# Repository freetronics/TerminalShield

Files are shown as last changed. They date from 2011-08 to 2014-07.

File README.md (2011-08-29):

Freetronics Terminal Shield
===========================
Copyright 2011 Freetronics Pty Ltd  
Freetronics site:  <www.freetronics.com>  
Freetronics email: <info@freetronics.com>  

A general-purpose prototyping shield for the Arduino Uno, Freetronics
Eleven, and other compatible boards based on the same header format,
with handy screw terminals for connecting external wires.

Features:

 * Reset button wired through to Arduino reset pin.
 * Red, green, and blue general-purpose SMT LEDs with current-limiting
   resistors (drive HIGH to illuminate).
 * Blue "power on" LED with current-limiting resistor.
 * Large GND and 5V power rails alongside the prototyping area.
 * 2 x 100nF bypass/smoothing capacitors on supply rails.
 * Overlay guide where you need it: both top and bottom.

More information is available on our product page at:

  http://www.freetronics.com/terminalshield

The "docs" folder within this repository includes a handy copy of the
schematic in PDF format and image(s) of the pcb.

INSTALLATION
------------
The design is saved as an EAGLE project. EAGLE PCB design software is
available from www.cadsoftusa.com free for non-commercial use. To use
this project download it and place the directory containing these files
into the "eagle" directory on your computer. Then open EAGLE and
navigate to Projects -> eagle -> TerminalShield.

DISTRIBUTION
------------
The specific terms of distribution of this project are governed by the
license referenced below.

LICENSE
-------
Licensed under the TAPR Open Hardware License (www.tapr.org/OHL).
The "license" folder within this repository also contains a copy of
this license in plain text format.

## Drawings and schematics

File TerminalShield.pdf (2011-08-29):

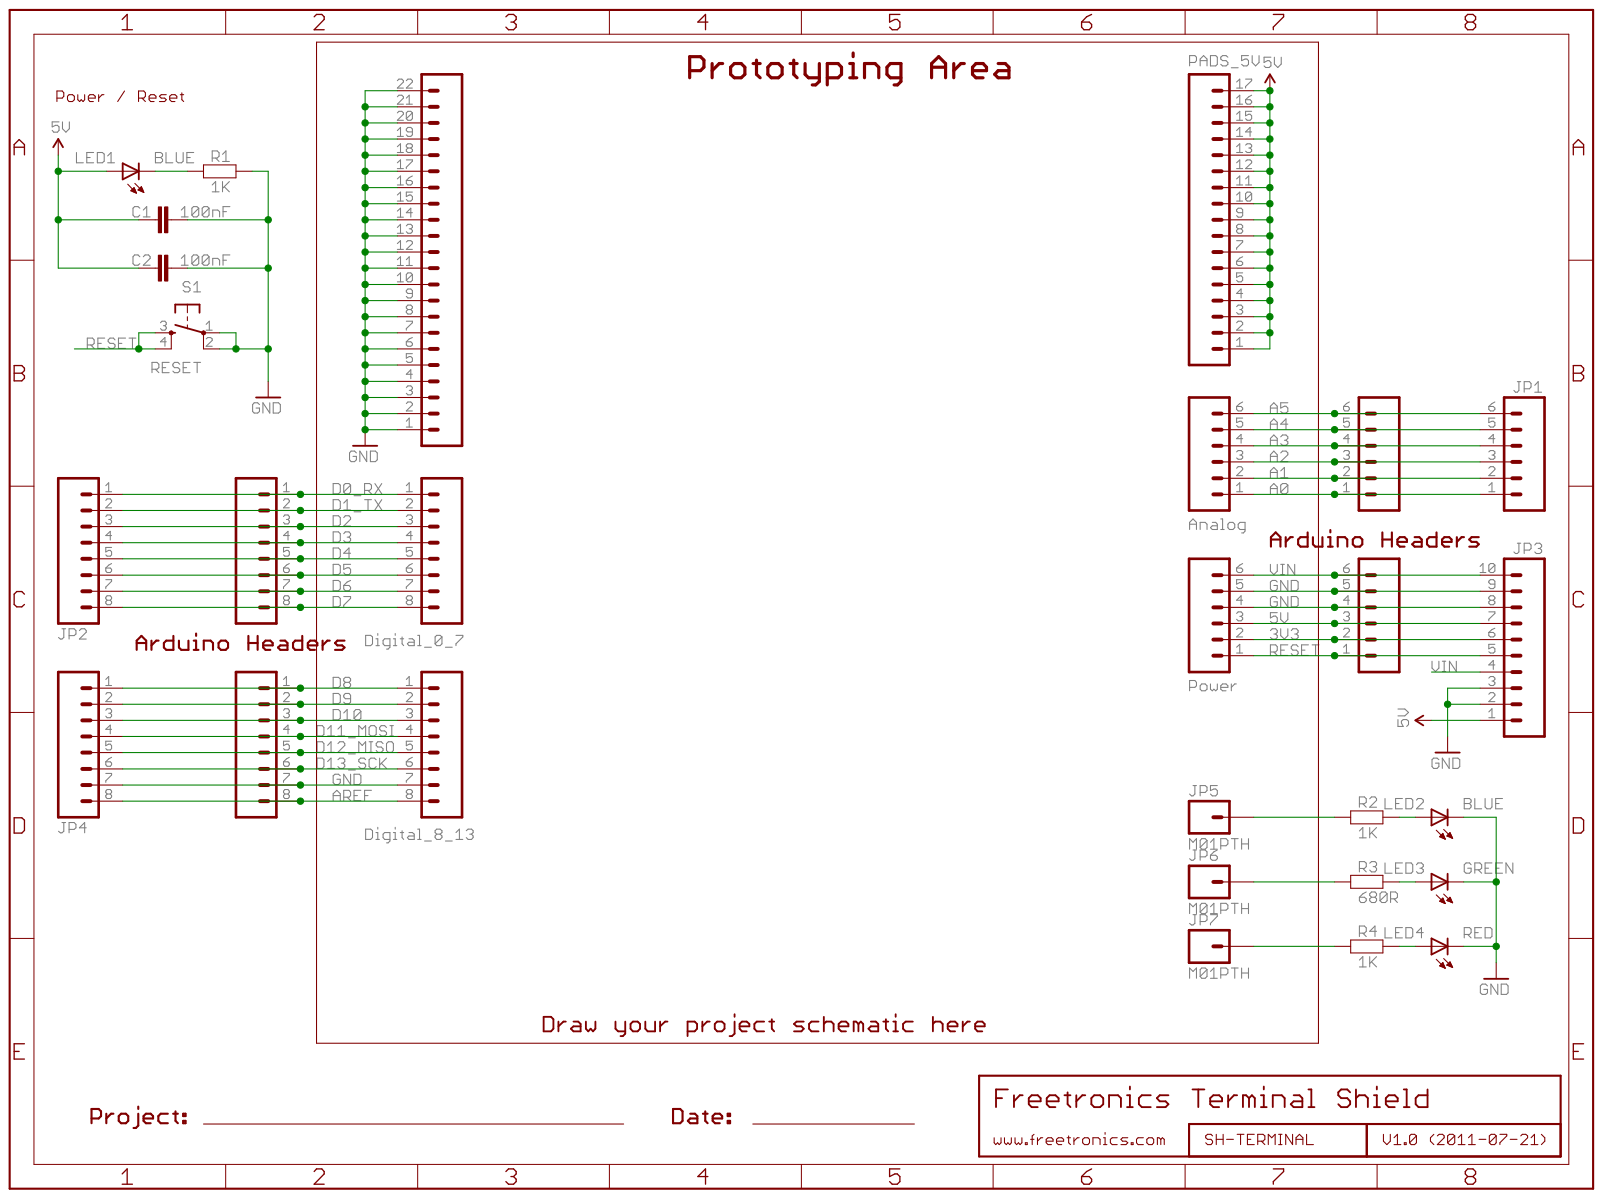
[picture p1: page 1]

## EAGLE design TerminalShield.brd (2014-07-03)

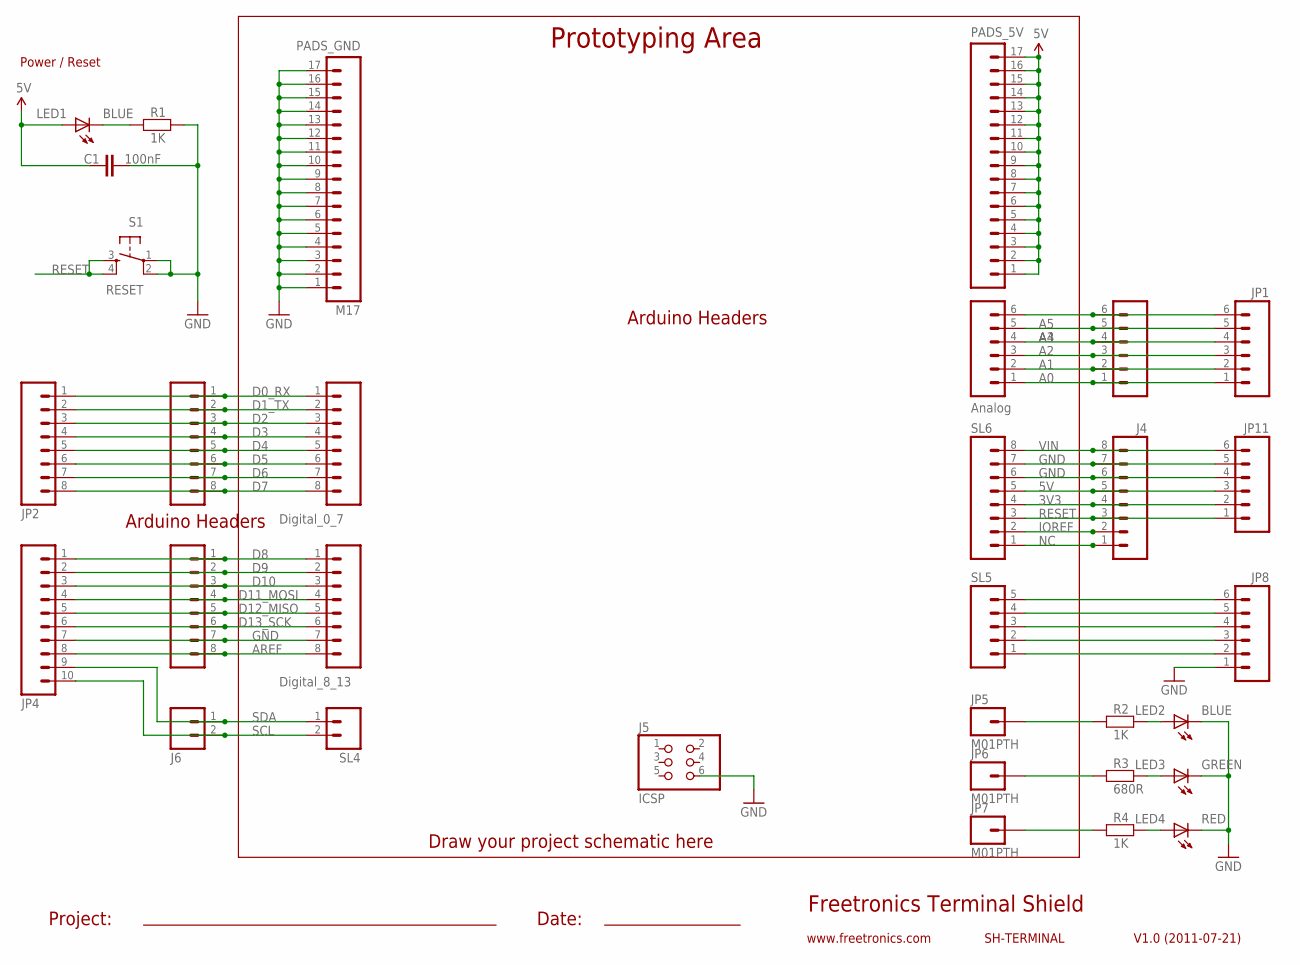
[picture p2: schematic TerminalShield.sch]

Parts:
C1: 100nF; 0603
J1: Analog; 1X06
J2: Digital_0_7; 1X08
J3: Digital_8_13; 1X08
J4: M08STD; 1X08
J5: ICSP; 2X03
J6: M02PTH; 1X02
JP1, JP8, JP11: M06; TERMINALBLOCK_3.5MM_6
JP2: M08; TERMINALBLOCK_3.5MM_8
JP4: M10; TERMINALBLOCK_3.5MM_10
JP5, JP6, JP7: M01PTH; 1X01
LED1, LED2: BLUE; LED-0603
LED3: GREEN; LED-0603
LED4: RED; LED-0603
PADS_5V: M17; 1X17
PADS_GND: M17; 1X17
R1, R2, R4: 1K; 0603
R3: 680R; 0603
S1: RESET; TACTILE_SWITCH_SMD
SL1: Analog; 1X06
SL2: Digital_0_7; 1X08
SL3: Digital_8_13; 1X08
SL4: M02PTH; 1X02
SL5: M05PTH; 1X05
SL6: M08STD; 1X08

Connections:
3V3: J4.4, JP11.2, SL6.4
5V: C1.1, J4.5, JP11.3, LED1.A, PADS_5V.1, PADS_5V.2, PADS_5V.3, PADS_5V.4, PADS_5V.5, PADS_5V.6, PADS_5V.7, PADS_5V.8, PADS_5V.9, PADS_5V.10, PADS_5V.11, PADS_5V.12, PADS_5V.13, PADS_5V.14, PADS_5V.15, PADS_5V.16, PADS_5V.17, SL6.5
A0: J1.1, JP1.1, SL1.1
A1: J1.2, JP1.2, SL1.2
A2: J1.3, JP1.3, SL1.3
A3: J1.4, JP1.4, SL1.4
A4: J1.5, JP1.5, SL1.5
A5: J1.6, JP1.6, SL1.6
AREF: J3.8, JP4.8, SL3.8
D0_RX: J2.1, JP2.1, SL2.1
D1_TX: J2.2, JP2.2, SL2.2
D2: J2.3, JP2.3, SL2.3
D3: J2.4, JP2.4, SL2.4
D4: J2.5, JP2.5, SL2.5
D5: J2.6, JP2.6, SL2.6
D6: J2.7, JP2.7, SL2.7
D7: J2.8, JP2.8, SL2.8
D8: J3.1, JP4.1, SL3.1
D9: J3.2, JP4.2, SL3.2
D10: J3.3, JP4.3, SL3.3
D11_MOSI: J3.4, JP4.4, SL3.4
D12_MISO: J3.5, JP4.5, SL3.5
D13_SCK: J3.6, JP4.6, SL3.6
GND: C1.2, J3.7, J4.6, J4.7, J5.6, JP4.7, JP8.1, JP11.4, JP11.5, LED2.C, LED3.C, LED4.C, PADS_GND.1, PADS_GND.2, PADS_GND.3, PADS_GND.4, PADS_GND.5, PADS_GND.6, PADS_GND.7, PADS_GND.8, PADS_GND.9, PADS_GND.10, PADS_GND.11, PADS_GND.12, PADS_GND.13, PADS_GND.14, PADS_GND.15, PADS_GND.16, PADS_GND.17, R1.2, S1.1, S1.2, SL3.7, SL6.6, SL6.7
IOREF: J4.2, SL6.2
unnamed: LED4.A, R4.2
unnamed: LED3.A, R3.2
unnamed: JP6.1, R3.1
unnamed: LED2.A, R2.2
unnamed: JP8.2, SL5.1
unnamed: JP8.3, SL5.2
unnamed: JP8.4, SL5.3
unnamed: JP8.5, SL5.4
unnamed: JP8.6, SL5.5
unnamed: LED1.C, R1.1
unnamed: JP5.1, R2.1
NC: J4.1, SL6.1
PADS_GND: JP7.1, R4.1
RESET: J4.3, JP11.1, S1.3, S1.4, SL6.3
SCL: J6.2, JP4.10, SL4.2
SDA: J6.1, JP4.9, SL4.1
VIN: J4.8, JP11.6, SL6.8

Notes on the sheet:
Prototyping Area
Freetronics Terminal Shield
V1.0 (2011-07-21)
www.freetronics.com
SH-TERMINAL
Power / Reset
Arduino Headers
Draw your project schematic here
Project:
Date:

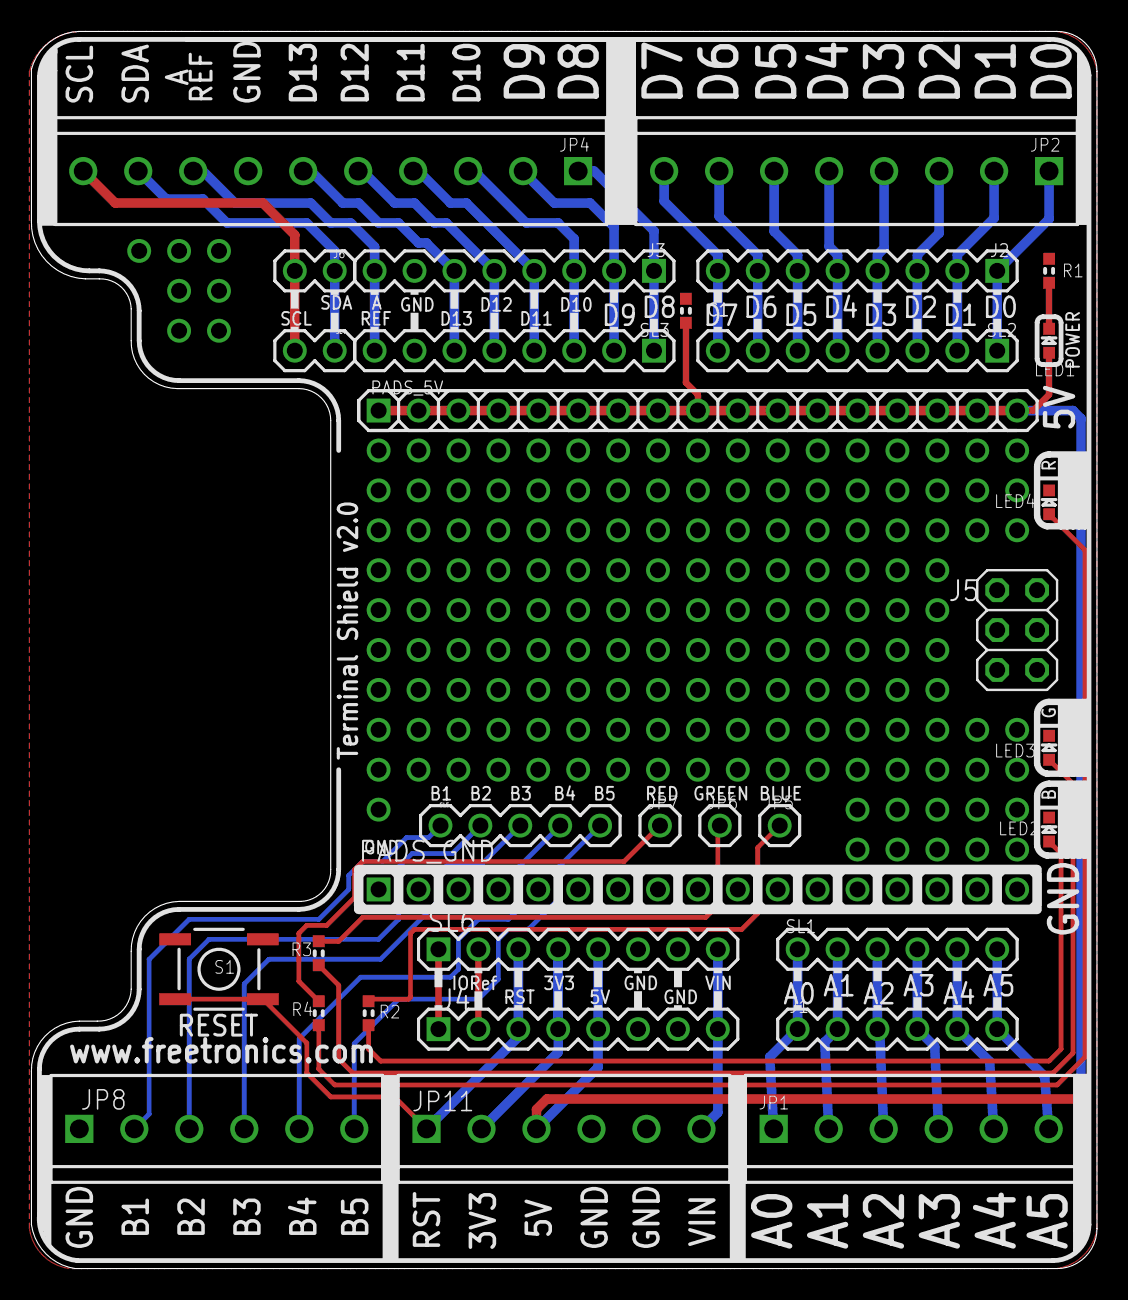
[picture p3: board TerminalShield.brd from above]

Board: 2 copper layers, 67.8 x 78.7 mm, 32 parts (0 on the bottom side), 42 nets.

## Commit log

2011-08-29 Initial import
    [TerminalShield.brd, TerminalShield.sch]
2011-08-29 Final production release
    [TerminalShield.brd, TerminalShield.sch]
2014-06-26 Update schematic for R3
    [TerminalShield.sch]
2014-07-03 TerminalShield v2.0 PCB (R3 compliant, ICSP, i2c on screw terminals, extra 5 pins of breakout screw terminals.)
    [TerminalShield.brd, TerminalShield.sch]

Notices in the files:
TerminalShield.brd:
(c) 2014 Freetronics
